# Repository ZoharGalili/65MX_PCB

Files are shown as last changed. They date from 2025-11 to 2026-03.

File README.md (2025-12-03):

# The65MX Keyboard PCB

a 65% keyboard pcb for use with my future keyboard projects.

## Features

### big components and BAV-70 diodes

I plan to assemble the pcb by hand to save costs as I have no problem putting the time to solder commponents by hand. for this reason i chose to not have any footprints smaller than an 0805 and also use BAV-70 dual diodes as i belive it will take less time to solder a single BAV-70 than two standard diodes.

### JST_SH daughterboard connector

I like the UBD-S daughterboard for case design but I have learned from a previous keyboard project that the molex EZmate connector is shit. I probably didnt solder it properly and it repeatedly snapped of the board. for this exact reason I desined the [UBD-S-JST](https://github.com/ZoharGalili/UDB-S-JST), a fork of the [UBD-S](https://github.com/Unified-Daughterboard/UDB-S) with a JST connecotr along with some ohter changes.

### QMK firmware and VIA support

the PCB uses an STM32f072 microcontroller. I have made a keyboard with this microcontroller before running QMK with VIA 

### bakeneko65 and ai03 vega board outline

I coppied the board outline of the bekeneko for supporting a gummy o-ring friction fit mount. I also took the board outline from the ai03 vega so the board can support an internally screwed case. 

### soldered MX switches

I have encountered problems before with the standard keilh hot swap sockets so i decided to make a solder pcb this time. mill max sockets exits so if I ever want to have a hotswap board I can pop those in.

### multilatout support

the board supports 6.25u or 7u spacebar, stepped caps lock and split backspace. this isnt the most layouts in a board but i feel like those are the layouts that I may want to use and I dont want to go crazy with layout support.

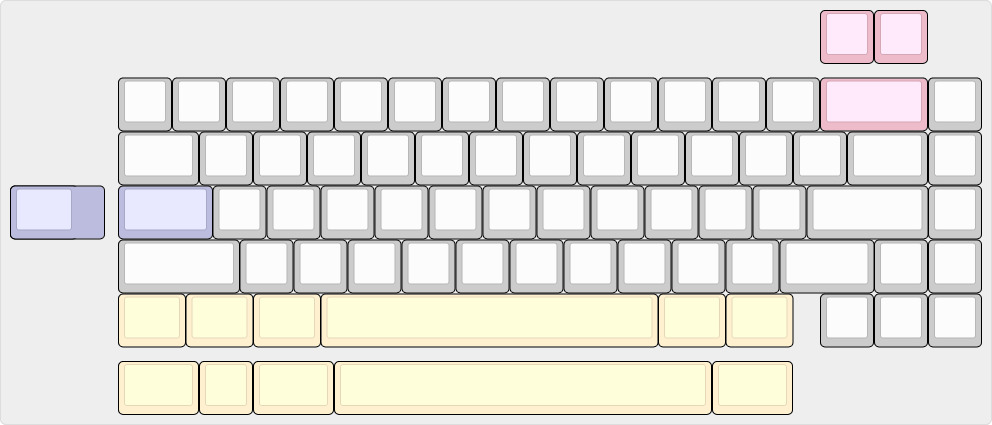
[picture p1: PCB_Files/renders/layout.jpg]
layout


## board renders

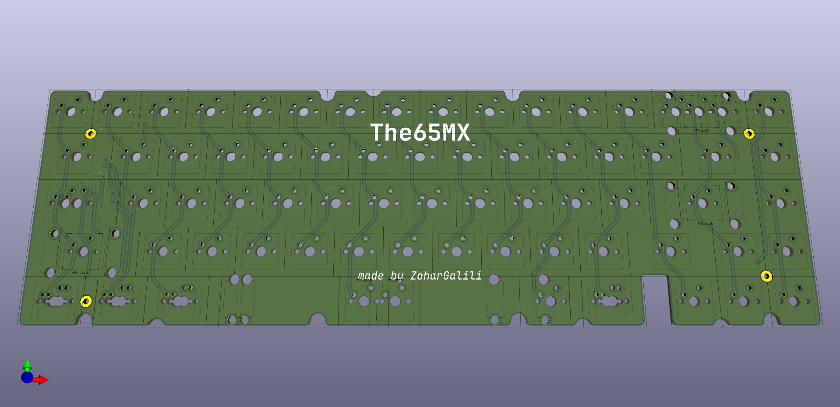
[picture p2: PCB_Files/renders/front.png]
front


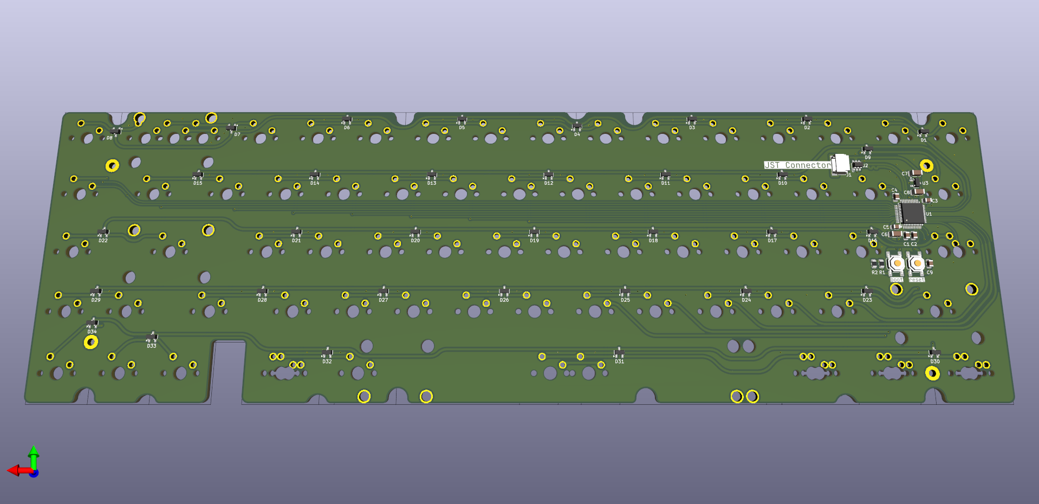
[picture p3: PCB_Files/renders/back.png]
back


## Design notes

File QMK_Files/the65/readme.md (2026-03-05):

# the65

the65

*A short description of the keyboard/project*

* Keyboard Maintainer: [ZoharGalili](https://github.com/ZoharGalili)
* Hardware Supported: *The PCBs, controllers supported*
* Hardware Availability: *Links to where you can find this hardware*

Make example for this keyboard (after setting up your build environment):

    make the65:default

Flashing example for this keyboard:

    make the65:default:flash

See the [build environment setup](https://docs.qmk.fm/#/getting_started_build_tools) and the [make instructions](https://docs.qmk.fm/#/getting_started_make_guide) for more information. Brand new to QMK? Start with our [Complete Newbs Guide](https://docs.qmk.fm/#/newbs).

## Bootloader

Enter the bootloader in 3 ways:

* **Bootmagic reset**: Hold down the key at (0,0) in the matrix (usually the top left key or Escape) and plug in the keyboard
* **Physical reset button**: Briefly press the button on the back of the PCB - some may have pads you must short instead
* **Keycode in layout**: Press the key mapped to `QK_BOOT` if it is available

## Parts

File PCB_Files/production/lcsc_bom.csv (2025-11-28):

Designator | Footprint | Quantity | Value | LCSC Part #
BOOT0, RST1 | SW_SPST_SKQG_WithStem | 2 | NRST | C318884
C1, C2, C3, C4, C5, C9 | 805 | 6 | 100n | C5137467
C6, C7, C8 | 1206 | 3 | 1u | C1848
D1, D10, D11, D12, D13, D14, D15, D16, D17, D18, D19, D2, D20, D21, D22, D23, D24, D25, D26, D27, D28, D29, D3, D30, D31, D32, D33, D34, D4, D5, D6, D7, D8, D9 | SOT-23 | 34 | BAV70_Small | C5341727
J1 | JST_SH_SM04B-SRSS-TB_1x04-1MP_P1.00mm_Horizontal | 1 | WAFER-SH1.0-4PWB | C3029343
R1, R2 | 805 | 2 | 5k1 | C27834
U1 | LQFP-48_7x7mm_P0.5mm | 1 | STM32F072CBTx | C81720
U2 | SOT-23-6-routable | 1 | SRV05-4 | C2836319
U3 | SOT-23-3 | 1 | XC6206PxxxMR | C347376

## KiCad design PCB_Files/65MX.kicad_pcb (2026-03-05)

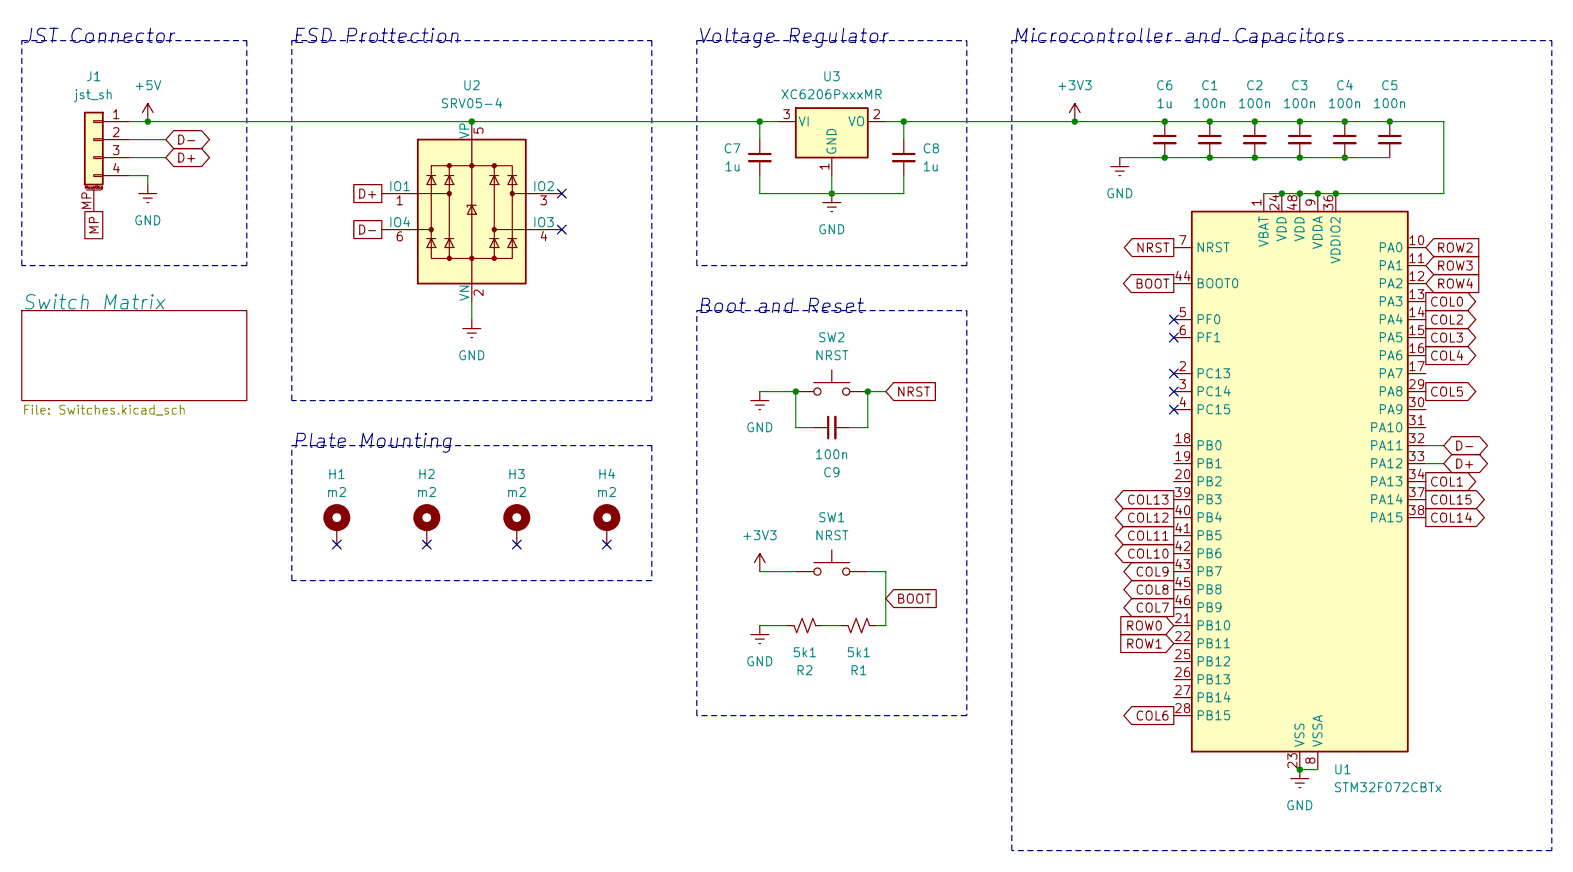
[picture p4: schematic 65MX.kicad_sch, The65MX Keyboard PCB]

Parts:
C1, C2, C3, C4, C5, C9: 100n; C_0805_2012Metric
C6, C7, C8: 1u; C_1206_3216Metric
H1, H2, H3, H4: m2; MountingHole_2.2mm_M2_Pad_TopBottom
J1: jst_sh; JST_SH_SM04B-SRSS-TB_1x04-1MP_P1.00mm_Horizontal
R1, R2: 5k1; R_0805_2012Metric
SW1, SW2: NRST; SW_SPST_SKQG_WithStem
U1: STM32F072CBTx; LQFP-48_7x7mm_P0.5mm
U2: SRV05-4; SOT-23-6-routable
U3: XC6206PxxxMR; SOT-23-3

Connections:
+3V3: C1.1, C2.1, C3.1, C4.1, C5.1, C6.1, C8.1, SW1.1, U1.1 (VBAT), U1.9 (VDDA), U1.24 (VDD), U1.36 (VDDIO2), U1.48 (VDD), U3.2 (VO)
+5V: C7.1, J1.1, U2.5 (VP), U3.3 (VI)
BOOT: R1.2, SW1.2, U1.44 (BOOT0)
COL0: U1.13 (PA3); also elsewhere on the board
COL1: U1.34 (PA13); also elsewhere on the board
COL2: U1.14 (PA4); also elsewhere on the board
COL3: U1.15 (PA5); also elsewhere on the board
COL4: U1.16 (PA6); also elsewhere on the board
COL5: U1.29 (PA8); also elsewhere on the board
COL6: U1.28 (PB15); also elsewhere on the board
COL7: U1.46 (PB9); also elsewhere on the board
COL8: U1.45 (PB8); also elsewhere on the board
COL9: U1.43 (PB7); also elsewhere on the board
COL10: U1.42 (PB6); also elsewhere on the board
COL11: U1.41 (PB5); also elsewhere on the board
COL12: U1.40 (PB4); also elsewhere on the board
COL13: U1.39 (PB3); also elsewhere on the board
COL14: U1.38 (PA15); also elsewhere on the board
COL15: U1.37 (PA14); also elsewhere on the board
D+: J1.3, U1.33 (PA12), U2.1 (IO1)
D-: J1.2, U1.32 (PA11), U2.6 (IO4)
GND: C1.2, C2.2, C3.2, C4.2, C5.2, C6.2, C7.2, C8.2, C9.1, J1.4, R2.1, SW2.1, U1.8 (VSSA), U1.23 (VSS), U1.35 (VSS), U1.47 (VSS), U2.2 (VN), U3.1 (GND)
MP: J1.MP (MountPin)
NRST: C9.2, SW2.2, U1.7 (NRST)
unnamed: R1.1, R2.2
ROW0: U1.21 (PB10); also elsewhere on the board
ROW1: U1.22 (PB11); also elsewhere on the board
ROW2: U1.10 (PA0); also elsewhere on the board
ROW3: U1.11 (PA1); also elsewhere on the board
ROW4: U1.12 (PA2); also elsewhere on the board

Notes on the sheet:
Microcontroller and Capacitors
Voltage Regulator
JST Connector
ESD Prottection
Plate Mounting
Boot and Reset

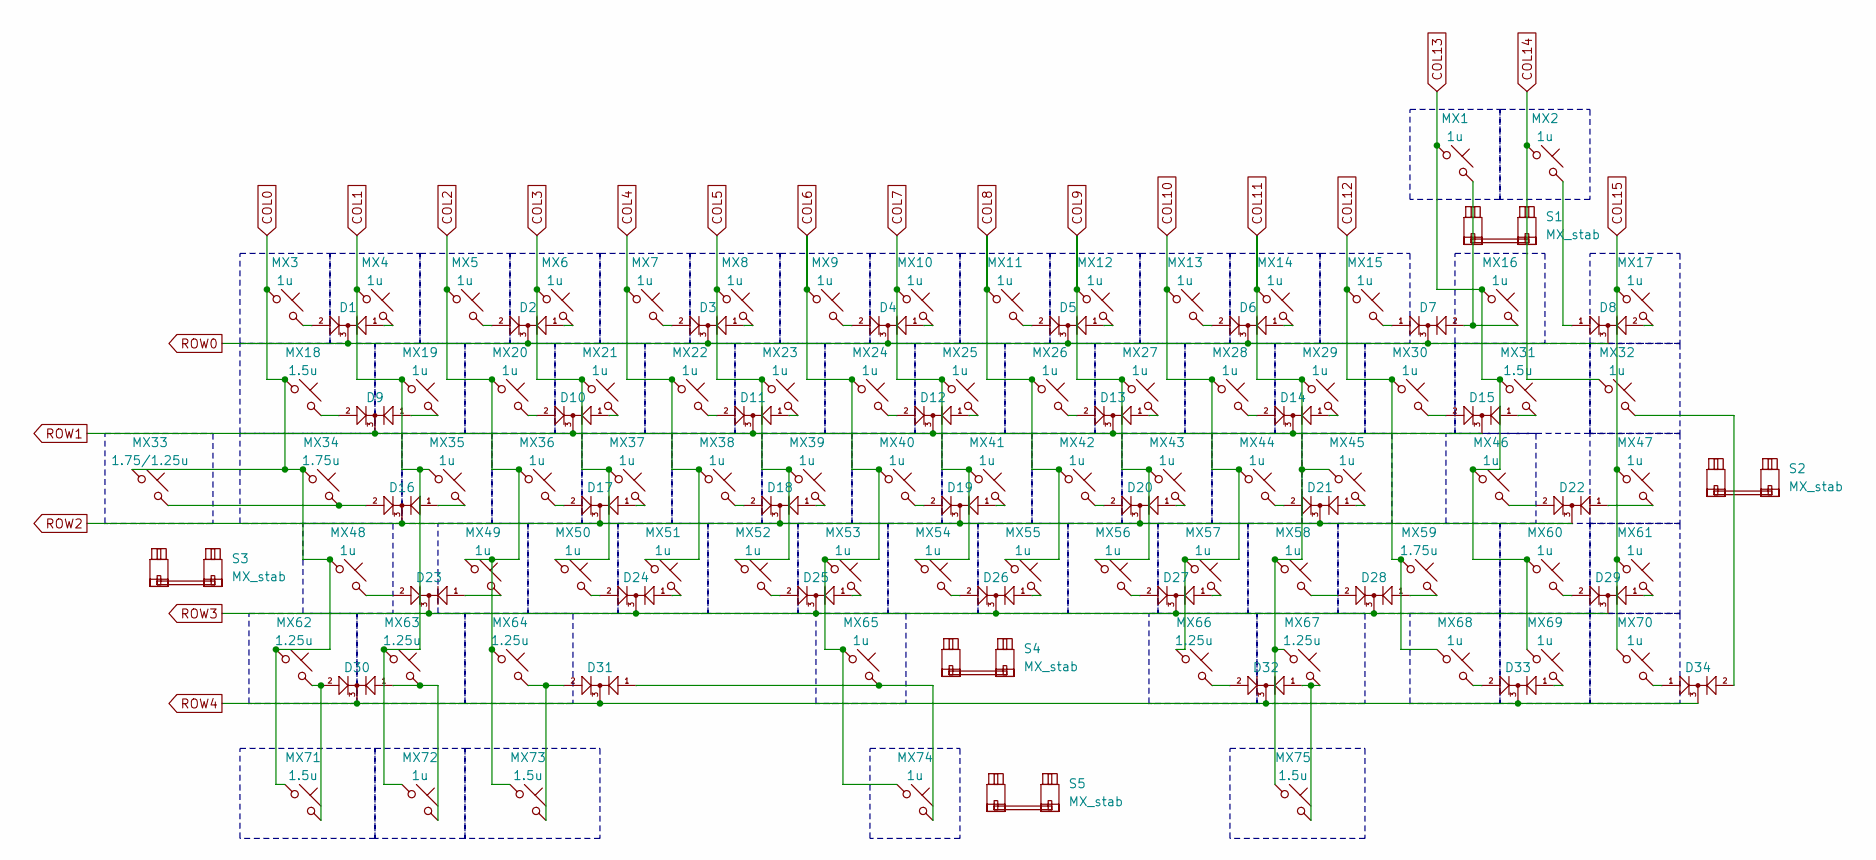
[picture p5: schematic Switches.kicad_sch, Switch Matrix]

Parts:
D1, D2, D3, D4, D5, D6, D7, D8, D9, D10, D11, D12, D13, D14, D15, D16, D17, D18, D19, D20, D21, D22, D23, D24, D25, D26, D27, D28, D29, D30, D31, D32, D33, D34: BAV70_Small; SOT-23
MX1, MX2, MX3, MX4, MX5, MX6, MX7, MX8, MX9, MX10, MX11, MX12, MX13, MX14, MX15, MX16, MX17, MX19, MX20, MX21, MX22, MX23, MX24, MX25, MX26, MX27, MX28, MX29, MX30, MX32, MX35, MX36, MX37, MX38, MX39, MX40, MX41, MX42, MX43, MX44, MX45, MX46, MX47, MX48, MX49, MX50, MX51, MX52, MX53, MX54, MX55, MX56, MX57, MX58, MX60, MX61, MX65, MX68, MX69, MX70, MX72, MX74: 1u; SW_MX_1u
MX18, MX31, MX71, MX73, MX75: 1.5u; SW_MX_1.5u
MX33: 1.75/1.25u; SW_MX_1.75u_STP_1.25
MX34, MX59: 1.75u; SW_MX_1.75u
MX62, MX63, MX64, MX66, MX67: 1.25u; SW_MX_1.25u
S1: MX_stab; STAB_MX_P_2u
S2, S3: MX_stab; STAB_MX_P_2.25u
S4: MX_stab; STAB_MX_P_6.25u
S5: MX_stab; STAB_MX_P_7u

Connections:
COL0: MX3.1, MX18.1, MX33.1, MX34.1, MX48.1, MX62.1, MX71.1; also elsewhere on the board
COL1: MX4.1, MX19.1, MX35.1, MX63.1, MX72.1; also elsewhere on the board
COL2: MX5.1, MX20.1, MX36.1, MX49.1, MX64.1, MX73.1; also elsewhere on the board
COL3: MX6.1, MX21.1, MX37.1, MX50.1; also elsewhere on the board
COL4: MX7.1, MX22.1, MX38.1, MX51.1; also elsewhere on the board
COL5: MX8.1, MX23.1, MX39.1, MX52.1; also elsewhere on the board
COL6: MX9.1, MX24.1, MX40.1, MX53.1, MX65.1, MX74.1; also elsewhere on the board
COL7: MX10.1, MX25.1, MX41.1, MX54.1; also elsewhere on the board
COL8: MX11.1, MX26.1, MX42.1, MX55.1; also elsewhere on the board
COL9: MX12.1, MX27.1, MX43.1, MX56.1; also elsewhere on the board
COL10: MX13.1, MX28.1, MX44.1, MX57.1, MX66.1; also elsewhere on the board
COL11: MX14.1, MX29.1, MX45.1, MX58.1, MX67.1, MX75.1; also elsewhere on the board
COL12: MX15.1, MX30.1, MX59.1, MX68.1; also elsewhere on the board
COL13: MX1.1, MX16.1, MX31.1, MX46.1, MX60.1, MX69.1; also elsewhere on the board
COL14: MX2.1, MX32.1; also elsewhere on the board
COL15: MX17.1, MX47.1, MX61.1, MX70.1; also elsewhere on the board
unnamed: D1.1 (A1), MX4.2
unnamed: D1.2 (A2), MX3.2
unnamed: D2.1 (A1), MX6.2
unnamed: D2.2 (A2), MX5.2
unnamed: D3.1 (A1), MX8.2
unnamed: D3.2 (A2), MX7.2
unnamed: D4.1 (A1), MX10.2
unnamed: D4.2 (A2), MX9.2
unnamed: D5.1 (A1), MX12.2
unnamed: D5.2 (A2), MX11.2
unnamed: D6.1 (A1), MX14.2
unnamed: D6.2 (A2), MX13.2
unnamed: D7.1 (A1), MX15.2
unnamed: D7.2 (A2), MX1.2, MX16.2
unnamed: D8.1 (A1), MX2.2
unnamed: D8.2 (A2), MX17.2
unnamed: D9.1 (A1), MX19.2
unnamed: D9.2 (A2), MX18.2
unnamed: D10.1 (A1), MX21.2
unnamed: D10.2 (A2), MX20.2
unnamed: D11.1 (A1), MX23.2
unnamed: D11.2 (A2), MX22.2
unnamed: D12.1 (A1), MX25.2
unnamed: D12.2 (A2), MX24.2
unnamed: D13.1 (A1), MX27.2
unnamed: D13.2 (A2), MX26.2
unnamed: D14.1 (A1), MX29.2
unnamed: D14.2 (A2), MX28.2
unnamed: D15.1 (A1), MX31.2
unnamed: D15.2 (A2), MX30.2
unnamed: D16.1 (A1), MX35.2
unnamed: D16.2 (A2), MX33.2, MX34.2
unnamed: D17.1 (A1), MX37.2
unnamed: D17.2 (A2), MX36.2
unnamed: D18.1 (A1), MX39.2
unnamed: D18.2 (A2), MX38.2
unnamed: D19.1 (A1), MX41.2
unnamed: D19.2 (A2), MX40.2
unnamed: D20.1 (A1), MX43.2
unnamed: D20.2 (A2), MX42.2
unnamed: D21.1 (A1), MX45.2
unnamed: D21.2 (A2), MX44.2
unnamed: D22.1 (A1), MX47.2
unnamed: D22.2 (A2), MX46.2
unnamed: D23.1 (A1), MX49.2
unnamed: D23.2 (A2), MX48.2
unnamed: D24.1 (A1), MX51.2
unnamed: D24.2 (A2), MX50.2
unnamed: D25.1 (A1), MX53.2
unnamed: D25.2 (A2), MX52.2
unnamed: D26.1 (A1), MX55.2
unnamed: D26.2 (A2), MX54.2
unnamed: D27.1 (A1), MX57.2
unnamed: D27.2 (A2), MX56.2
unnamed: D28.1 (A1), MX59.2
unnamed: D28.2 (A2), MX58.2
unnamed: D29.1 (A1), MX61.2
unnamed: D29.2 (A2), MX60.2
unnamed: D30.1 (A1), MX63.2, MX72.2
unnamed: D30.2 (A2), MX62.2, MX71.2
unnamed: D31.1 (A1), MX65.2, MX74.2
unnamed: D31.2 (A2), MX64.2, MX73.2
unnamed: D32.1 (A1), MX67.2, MX75.2
unnamed: D32.2 (A2), MX66.2
unnamed: D33.1 (A1), MX69.2
unnamed: D33.2 (A2), MX68.2
unnamed: D34.1 (A1), MX70.2
unnamed: D34.2 (A2), MX32.2
ROW0: D1.3 (K), D2.3 (K), D3.3 (K), D4.3 (K), D5.3 (K), D6.3 (K), D7.3 (K), D8.3 (K); also elsewhere on the board
ROW1: D9.3 (K), D10.3 (K), D11.3 (K), D12.3 (K), D13.3 (K), D14.3 (K), D15.3 (K); also elsewhere on the board
ROW2: D16.3 (K), D17.3 (K), D18.3 (K), D19.3 (K), D20.3 (K), D21.3 (K), D22.3 (K); also elsewhere on the board
ROW3: D23.3 (K), D24.3 (K), D25.3 (K), D26.3 (K), D27.3 (K), D28.3 (K), D29.3 (K); also elsewhere on the board
ROW4: D30.3 (K), D31.3 (K), D32.3 (K), D33.3 (K), D34.3 (K); also elsewhere on the board

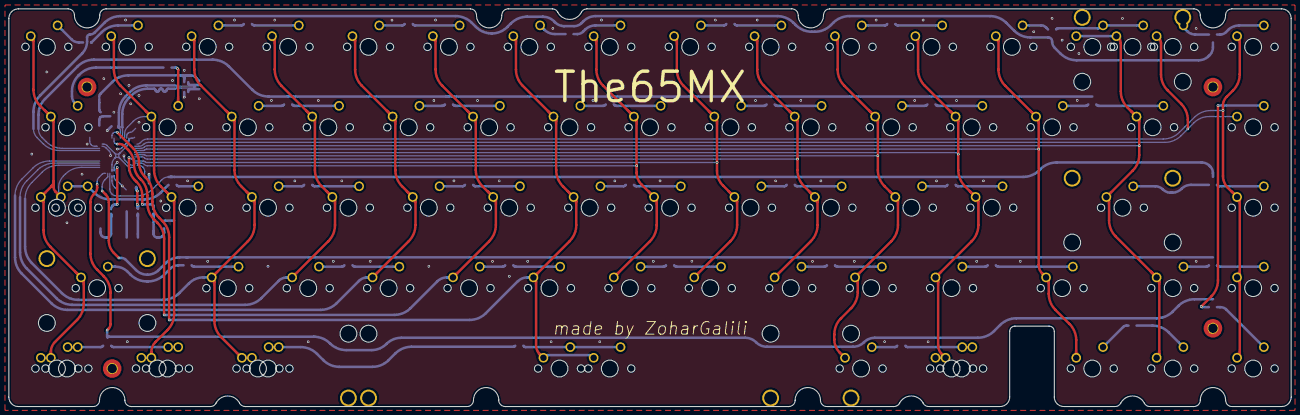
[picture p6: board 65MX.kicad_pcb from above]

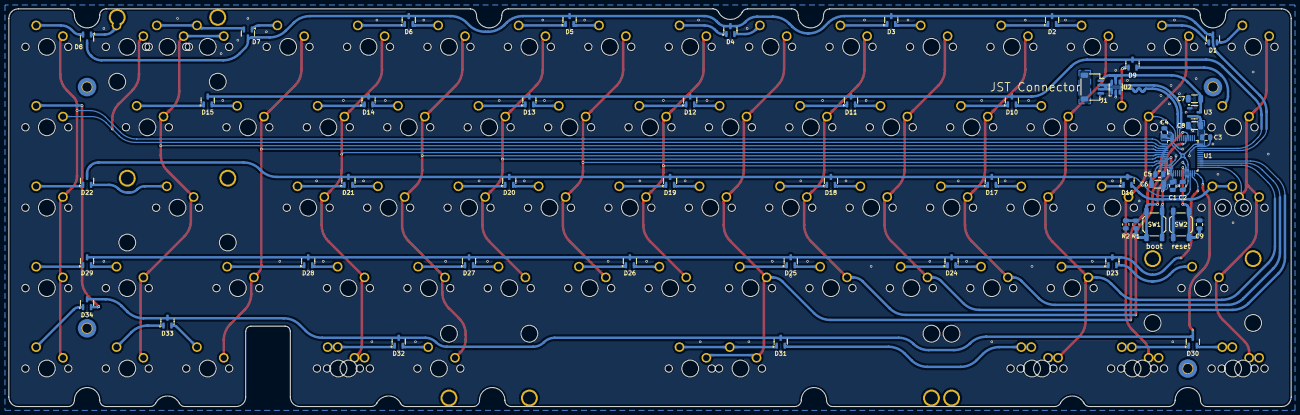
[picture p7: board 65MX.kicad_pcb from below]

Board: 2 copper layers, 303.8 x 94.2 mm, 135 parts (51 on the bottom side), 97 nets.

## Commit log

2025-11-28 made a pcb!
    [65MX.kicad_pcb, 65MX.kicad_sch, Switches.kicad_sch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]
2025-11-29 made a readme
    [65MX.kicad_pcb]
2025-12-02 Boot+Reset silkscreen
    added a silkscreen next to the boot and reset switches to differentiate between then
    [65MX.kicad_pcb]
2025-12-03 moved plate holes
    moved plate holes to enable proper gummy o ring mounting
    [65MX.kicad_pcb, positions.csv]
2026-03-05 added firmware
    added the qmk firmware files to the repo
    [65MX.kicad_pcb]
